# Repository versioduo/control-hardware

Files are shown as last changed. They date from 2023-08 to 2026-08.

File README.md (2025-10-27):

# control-hardware

⚙️ Instrument Controller

## Board

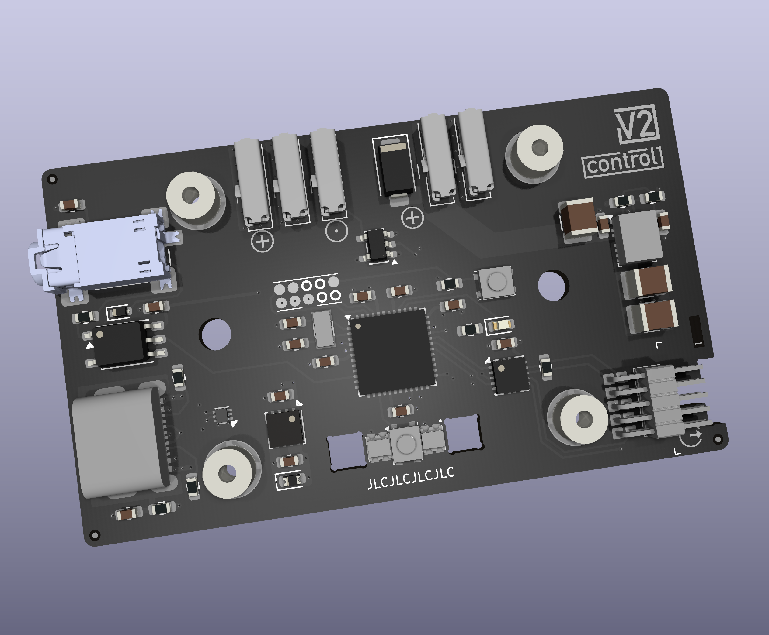
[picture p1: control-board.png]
board


## Schematic

[PDF](control.pdf)

## Bill Of Materials

[Interactive BOM](https://htmlpreview.github.io/?https://github.com/versioduo/control-hardware/main/control-bom.html)

# Copying
Anyone can use this public domain work without having to seek authorisation, no one can ever own it.

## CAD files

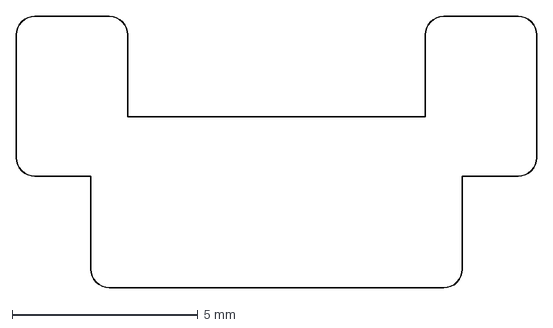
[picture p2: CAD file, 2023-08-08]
button-laser.dxf
14.0 x 7.30 mm

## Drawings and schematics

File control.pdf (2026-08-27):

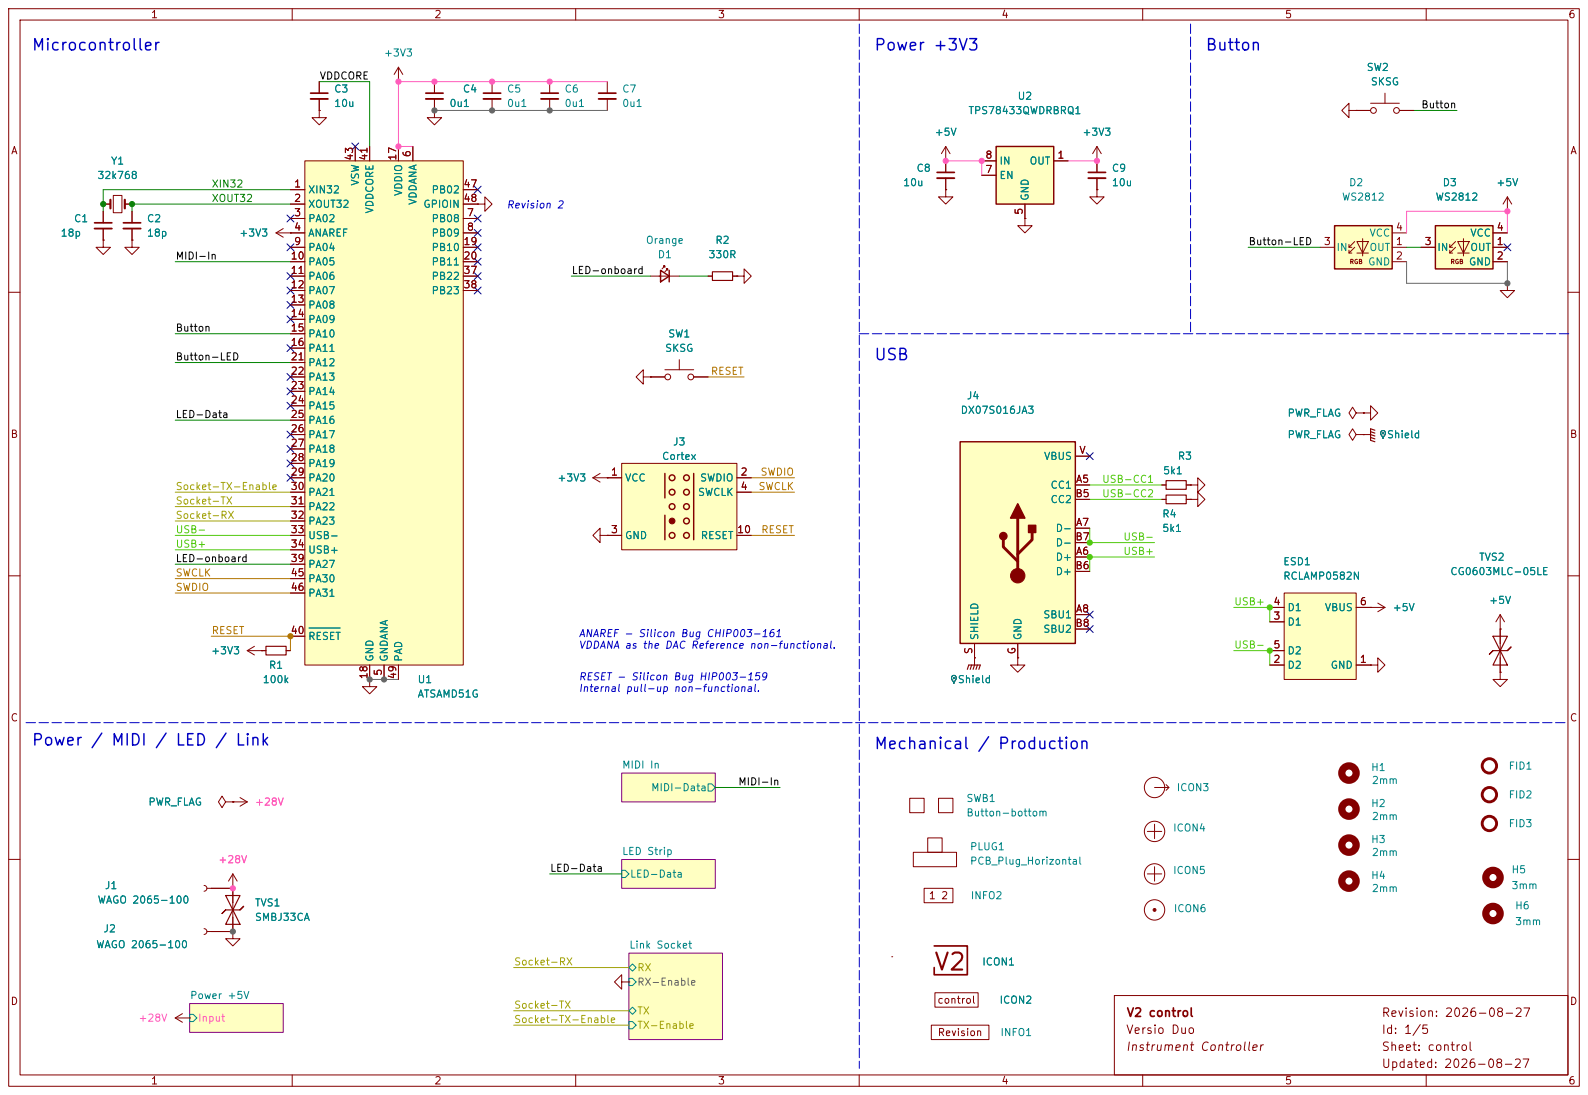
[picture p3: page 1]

VDDANA as the DAC Reference non-functional. Microcontroller

Button Socket-RX USB-

LED Strip MIDI-Data MIDI In +3V3

MIDI-In Button-LED
LED-onboard SWCLK

Internal pull-up non-functional. ANAREF - Silicon Bug CHIP003-161

Link Socket LED-Data

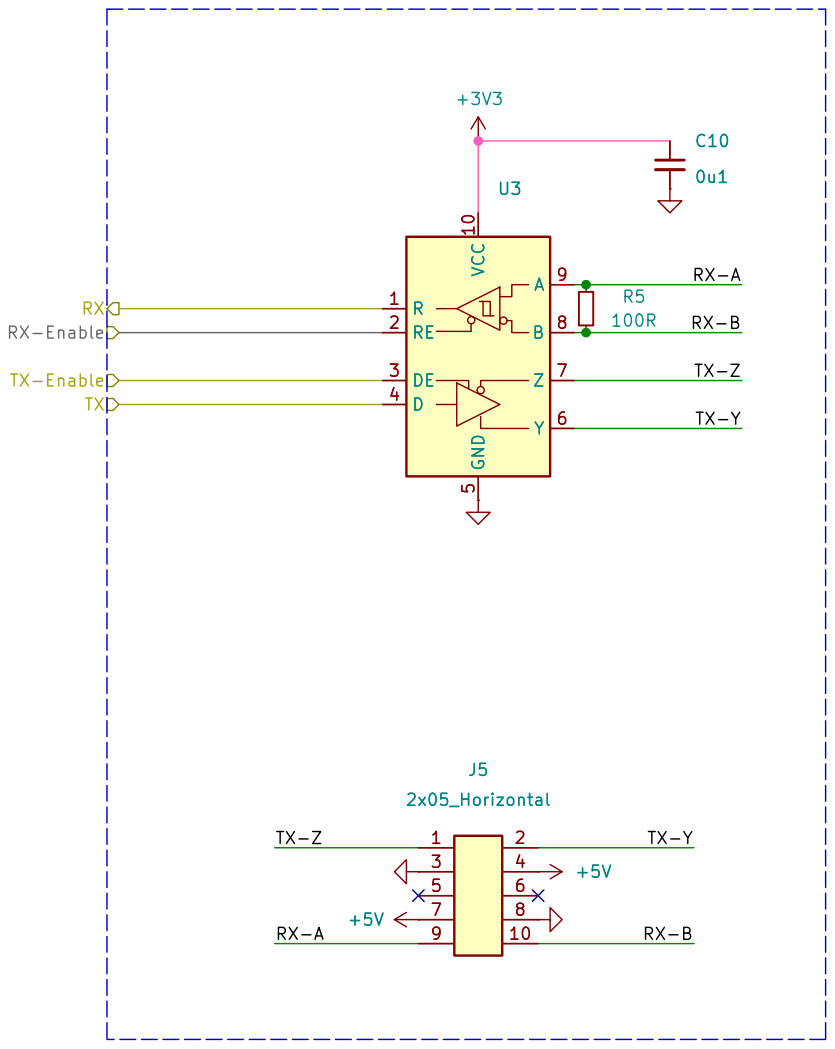
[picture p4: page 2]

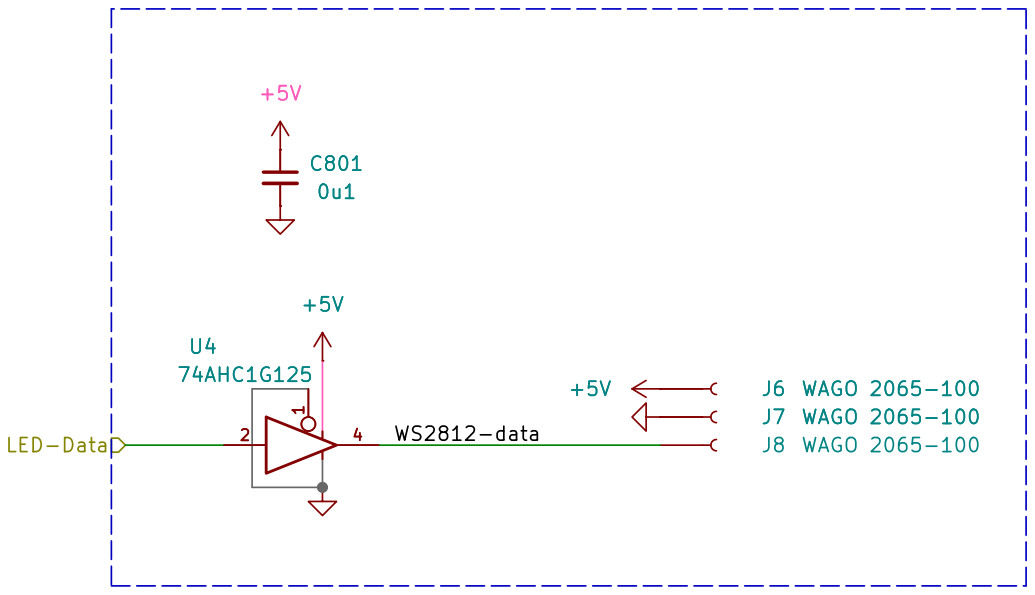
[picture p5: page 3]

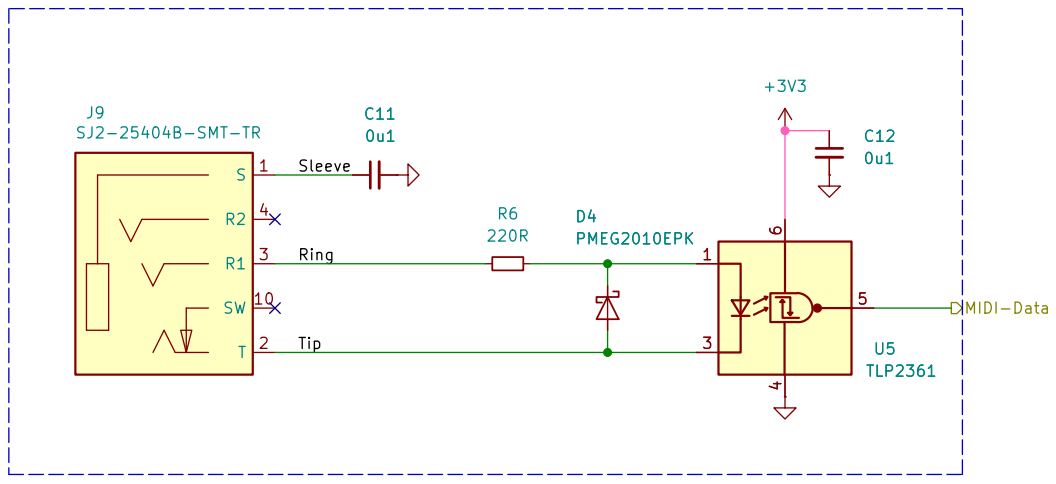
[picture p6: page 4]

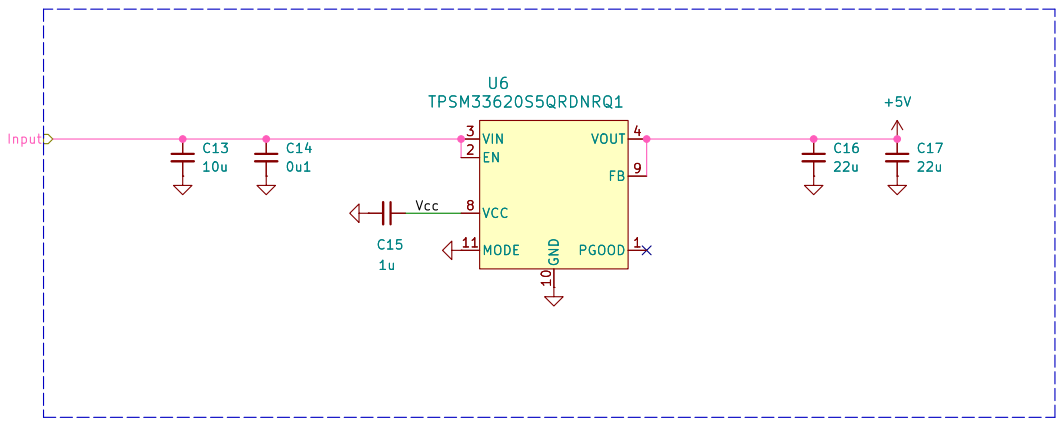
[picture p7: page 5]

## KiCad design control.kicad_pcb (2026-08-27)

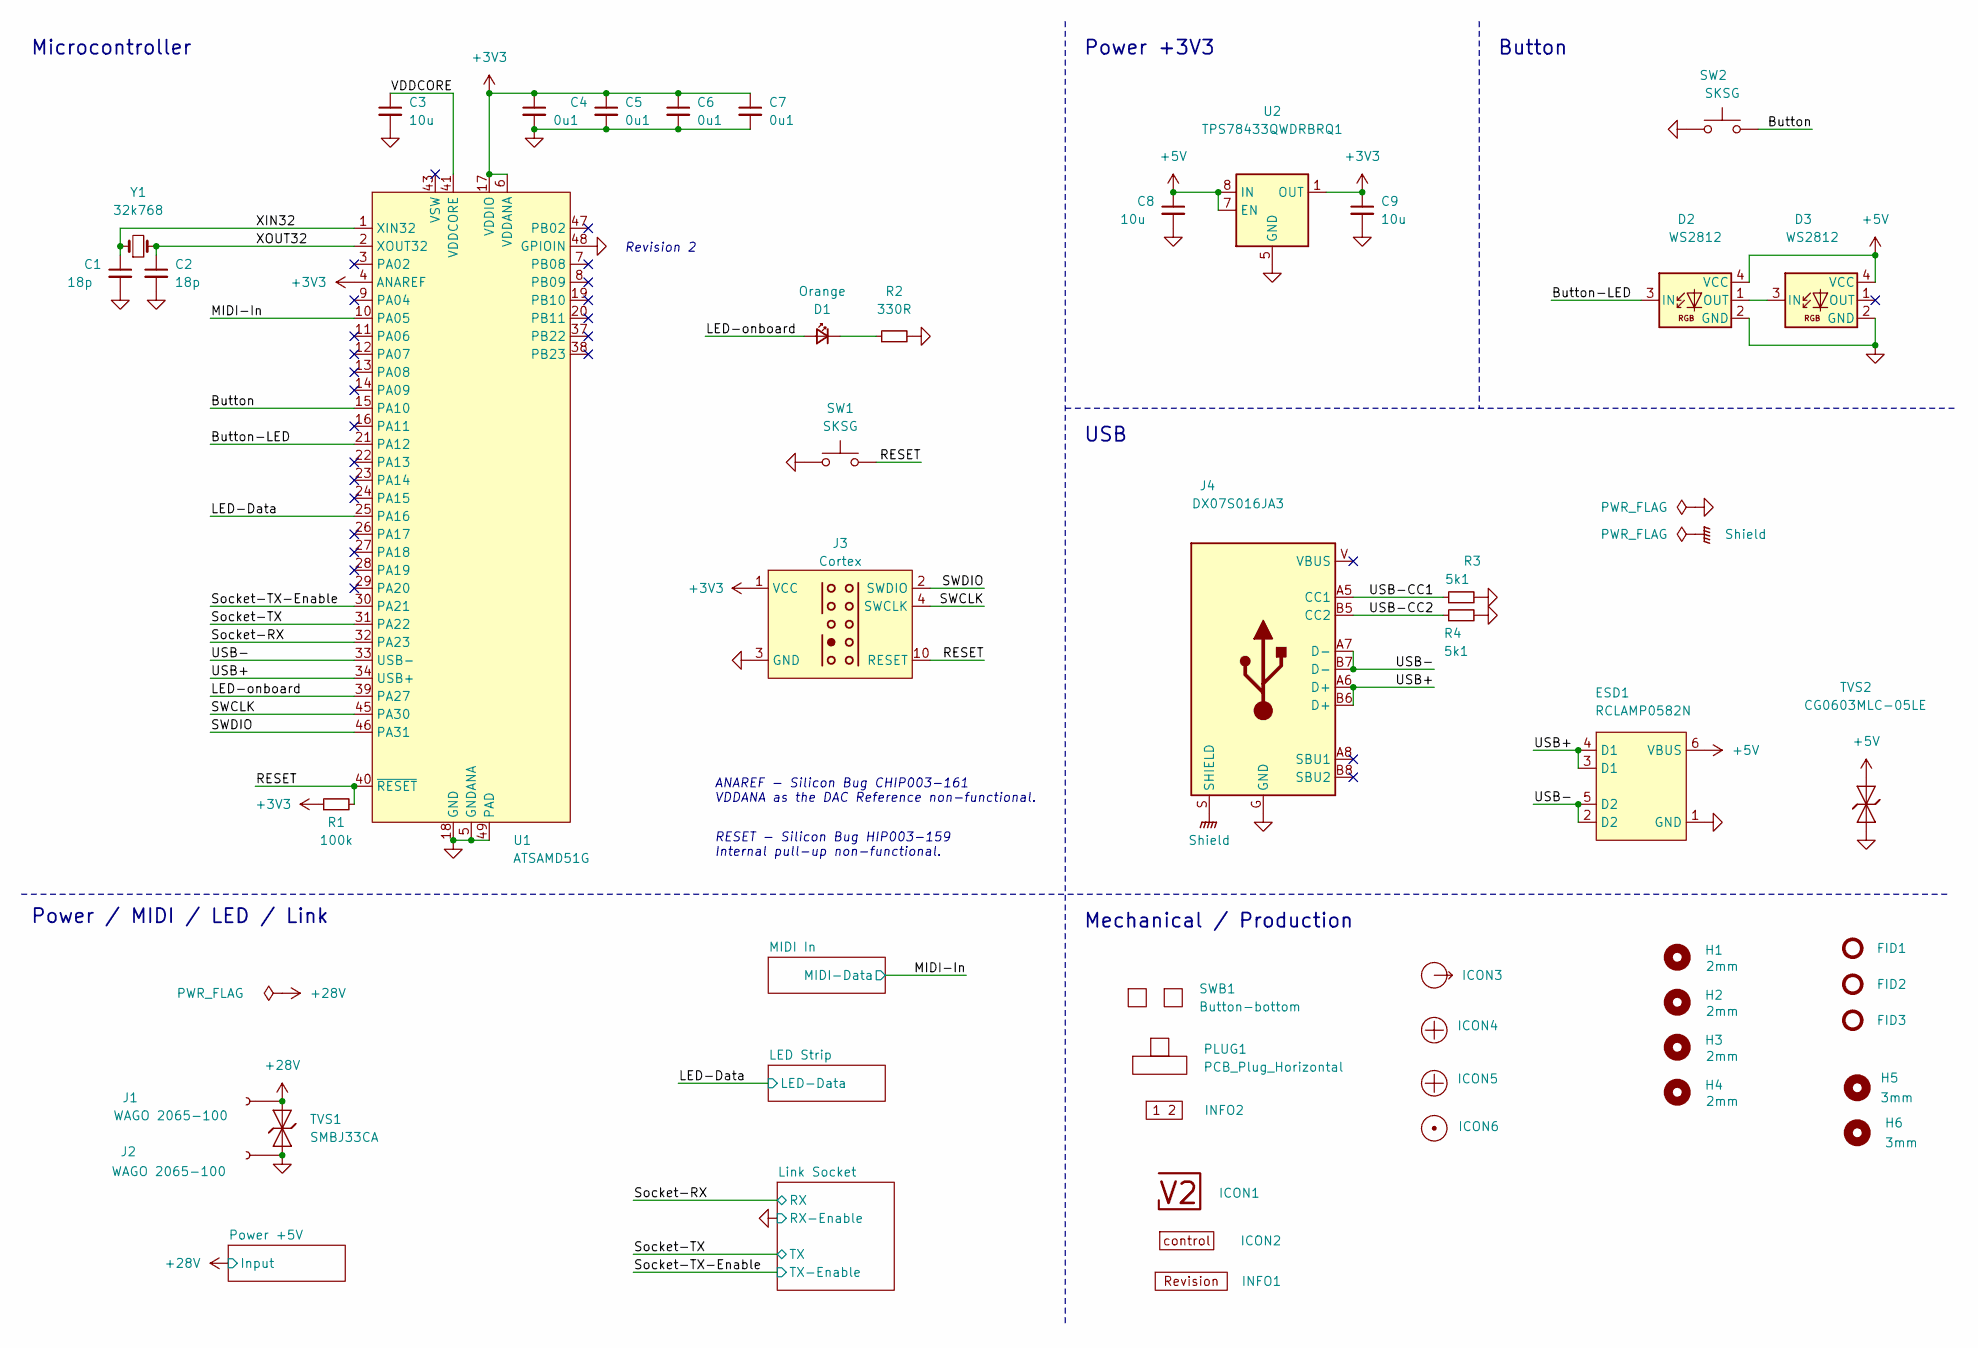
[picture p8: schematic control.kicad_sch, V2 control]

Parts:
C1, C2: 18p; C_1608; Rating 50V; Mouser 810-CGA3E2C0G1H180J
C3: 10u; C_1608; Rating 10V; Mouser 810-C1608X6S1A106M
C4, C5, C6, C7: 0u1; C_1608; Rating 50V; Mouser 810-CGA3E2X7R1H104MA
C8, C9: 10u; C_2012; Rating 25V; Mouser 810-C2012X5R1E106K
D1: Orange; LED_1608; Rating 605nm; Mouser 755-SML-D12D1WT86
D2, D3: WS2812; WS2812-2020; Rating 15mA; LCSC C965555
ESD1: RCLAMP0582N; SLP1210N6; Rating 20kV; Mouser 947-RCLAMP0582N.TCT
FID1, FID2, FID3: Fiducial_Paste; Fiducial_0.5mm_Mask1mm_Paste
H1, H2, H3, H4: 2mm; MountingHole_2mm
H5, H6: 3mm; MountingHole_3mm
ICON1: V2-logo; Logo_Small
ICON2: Board_control; Board_control_Small
ICON3: Arrow_Out
ICON4, ICON5: Plus; Plus_Small
ICON6: Dot; Dot_Small
INFO1: Revision
INFO2: Layer_Numbers-4
J1, J2: WAGO 2065-100; 2065-100; Rating 9A
J3: Cortex
J4: DX07S016JA3; JAE_DX07S016JA3; Rating USB2.0; Mouser 656-DX07S016JA3R1500
PLUG1: PCB_Plug_Horizontal
R1: 100k; R_1608; Rating 100mW; Mouser 71-CRCW0603100KFKEAC
R2: 330R; R_1608; Rating 100mW; Mouser 71-CRCW0603330RFKEAC
R3, R4: 5k1; R_1608; Rating 100mW; Mouser 71-CRCW06035K10FKEAC
SW1, SW2: SKSG; Rating 1.6N; Mouser 688-SKSGACE010
SWB1: Button-bottom; PCB_Button-bottom
TVS1: SMBJ33CA; D_SMB; Rating 33V; Mouser 652-SMBJ33CA-Q
TVS2: CG0603MLC-05LE; D_1608; Rating 5V; Mouser 652-CG0603MLC-05LE
U1: ATSAMD51G; QFN-48-1EP_7x7mm_P0.5mm_EP5.45x5.45mm_ThermalVias; Rating Cortex-M4F; Mouser 556-ATSAMD51G19AMU
U2: TPS78433QWDRBRQ1; VSON-8-1_3x3mm_P0.65_EP1.65x2.4mm; Rating 300mA; Mouser 595-TPS78433QWDRBRQ1
Y1: 32k768; Crystal_SMD_3215-2Pin_3.2x1.5mm; Rating 10ppm; Mouser 815-ABS0716632.768KT

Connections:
+3V3: C4.1, C5.1, C6.1, C7.1, C9.1, J3.1 (VCC), R1.1, U1.4 (ANAREF), U1.6 (VDDANA), U1.17 (VDDIO), U1.36 (VDDIO), U1.44 (VDDIO), U2.1 (OUT); also elsewhere on the board
+5V: C8.1, D2.4 (VCC), D3.4 (VCC), ESD1.6 (VBUS), TVS2.2 (A), U2.6 (EN), U2.7 (EN), U2.8 (IN); also elsewhere on the board
+28V: J1.1, TVS1.2 (A); also elsewhere on the board
/Button: SW2.2, U1.15 (PA10)
/Button-LED: D2.3 (IN), U1.21 (PA12)
/LED-Data: U1.25 (PA16); also elsewhere on the board
/LED-onboard: D1.2 (A), U1.39 (PA27)
/MIDI-In: U1.10 (PA05); also elsewhere on the board
/RESET: J3.10 (RESET), R1.2, SW1.2, U1.40 (~RESET)
/SWCLK: J3.4 (SWCLK), U1.45 (PA30)
/SWDIO: J3.2 (SWDIO), U1.46 (PA31)
/Shield: J4.S (SHIELD)
/Socket-RX: U1.32 (PA23); also elsewhere on the board
/Socket-TX: U1.31 (PA22); also elsewhere on the board
/Socket-TX-Enable: U1.30 (PA21); also elsewhere on the board
/USB+: ESD1.3 (D1), ESD1.4 (D1), J4.A6 (D+), J4.B6 (D+), U1.34 (USB+)
/USB-: ESD1.2 (D2), ESD1.5 (D2), J4.A7 (D-), J4.B7 (D-), U1.33 (USB-)
/USB-CC1: J4.A5 (CC1), R3.1
/USB-CC2: J4.B5 (CC2), R4.1
/VDDCORE: C3.1, U1.41 (VDDCORE)
/XIN32: C1.1, U1.1 (XIN32), Y1.1
/XOUT32: C2.1, U1.2 (XOUT32), Y1.2
GND: C1.2, C2.2, C3.2, C4.2, C5.2, C6.2, C7.2, C8.2, C9.2, D2.2 (GND), D3.2 (GND), ESD1.1 (GND), J2.1, J3.3 (GND), J3.5 (GND), J4.G (GND), R2.2, R3.2, R4.2, SW1.1, SW2.1, TVS1.1 (K), TVS2.1 (K), U1.5 (GNDANA), U1.18 (GND), U1.35 (GND), U1.42 (GND), U1.48 (GPIOIN), U1.49 (PAD), U2.5 (GND), U2.9 (GND); also elsewhere on the board
unnamed: D1.1 (K), R2.1
unnamed: D2.1 (OUT), D3.3 (IN)

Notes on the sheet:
ANAREF -  Silicon Bug CHIP003-161 VDDANA as the DAC Reference non-functional.
Power / MIDI / LED / Link
RESET -  Silicon Bug HIP003-159 Internal pull-up non-functional.
Button
Revision 2
Power +3V3
Mechanical / Production
Microcontroller
USB

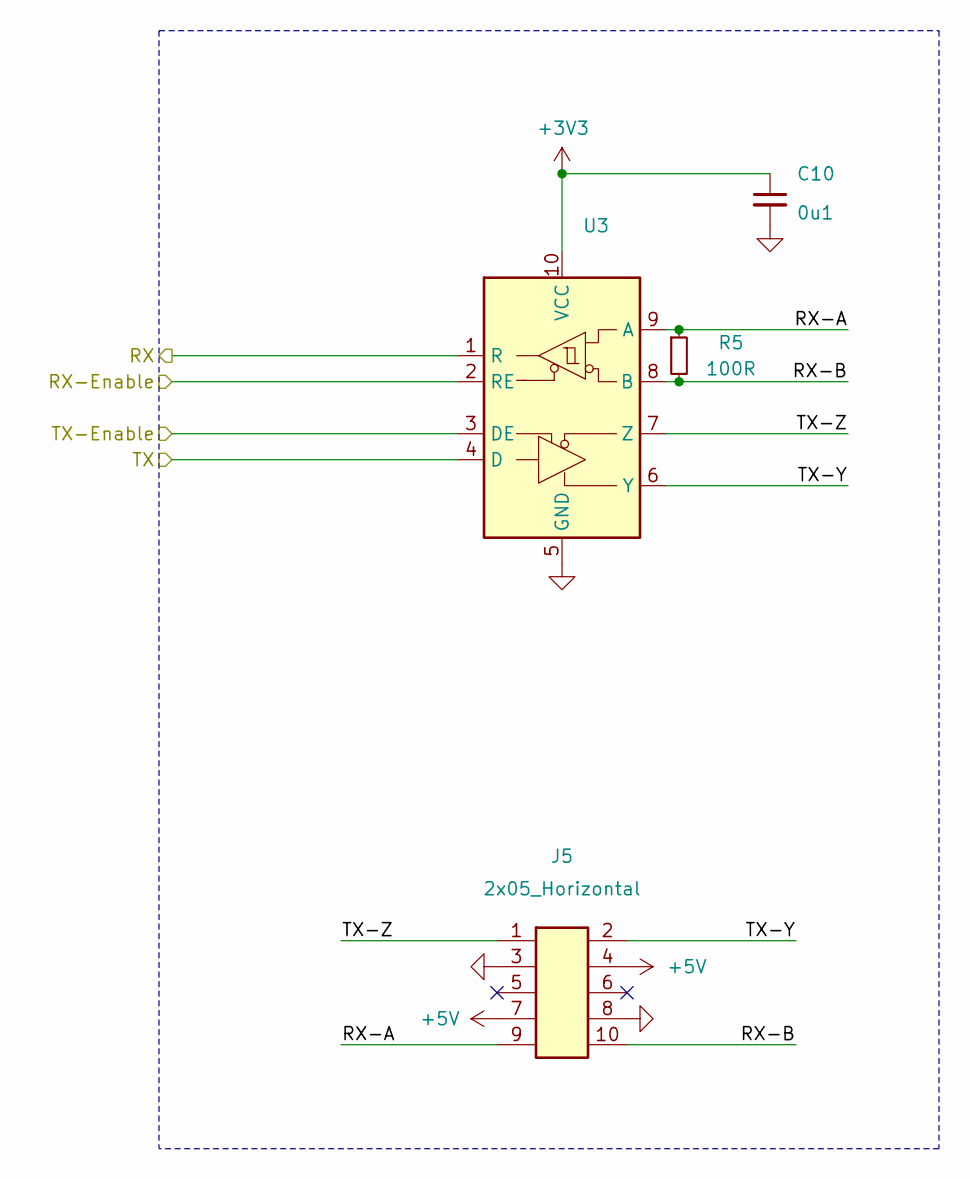
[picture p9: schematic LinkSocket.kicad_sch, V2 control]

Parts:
C10: 0u1; C_1608; Rating 50V; Mouser 810-CGA3E2X7R1H104MA
J5: 2x05_Horizontal; PinHeader_2x05_P1.27mm_Horizontal; Rating 1A; Mouser 649-200211120001T4LF
R5: 100R; R_1608; Rating 330mW; Mouser 71-CRCW0603100RFKEAH
U3: VSON-10-4-1EP_3x3mm_P0.5mm_EP1.65x2.4mm_ThermalVias

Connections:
+3V3: C10.1, U3.10 (VCC); also elsewhere on the board
+5V: J5.4, J5.7; also elsewhere on the board
/Link Socket/RX-A: J5.9, R5.1, U3.9 (A)
/Link Socket/RX-B: J5.10, R5.2, U3.8 (B)
/Link Socket/TX-Y: J5.2, U3.6 (Y)
/Link Socket/TX-Z: J5.1, U3.7 (Z)
/Socket-RX: U3.1 (R); also elsewhere on the board
/Socket-TX: U3.4 (D); also elsewhere on the board
/Socket-TX-Enable: U3.3 (DE); also elsewhere on the board
GND: C10.2, J5.3, J5.8, U3.2 (RE), U3.5 (GND), U3.11 (GND); also elsewhere on the board

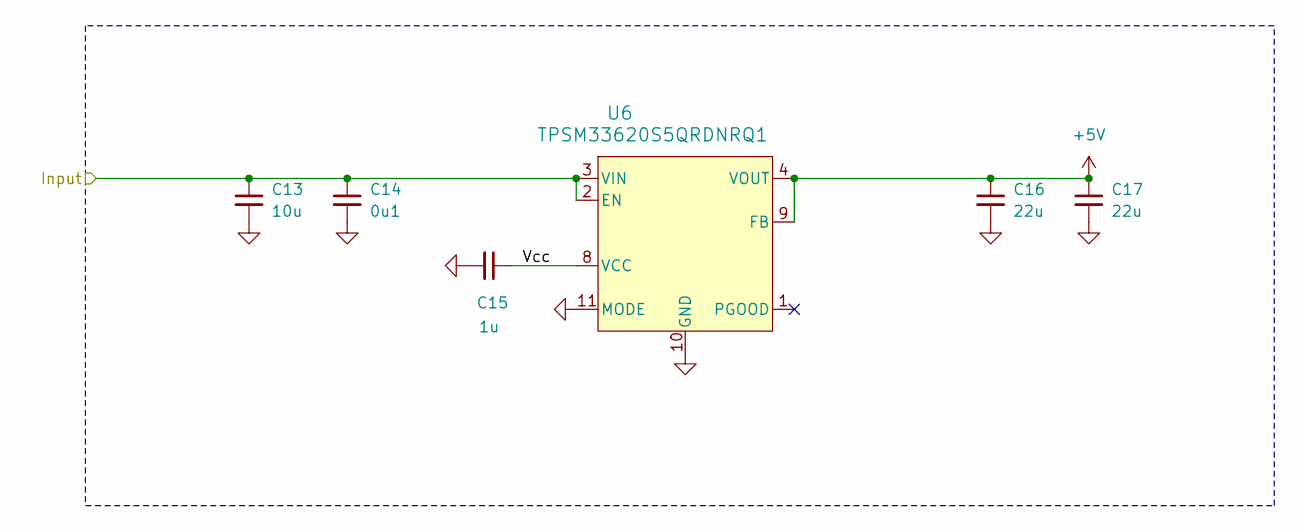
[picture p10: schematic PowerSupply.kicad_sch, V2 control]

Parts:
C13: 10u; C_3225; Rating 50V; Mouser 810-CNC6P1X7R1H106K2
C14: 0u1; C_1608; Rating 50V; Mouser 810-CGA3E2X7R1H104MA
C15: 1u; C_1608; Rating 50V; Mouser 810-CGA3E3X7R1H105K0
C16, C17: 22u; C_3225; Rating 25V; Mouser 810-CGA6P3X7R1E226M5
U6: TPSM33620S5QRDNRQ1; QFN-11; Rating 2A; Mouser 595-SM33620S5QRDNRQ1

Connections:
+5V: C16.1, C17.1, U6.4 (VOUT), U6.9 (FB); also elsewhere on the board
+28V: C13.1, C14.1, U6.2 (EN), U6.3 (VIN); also elsewhere on the board
/Power +5V/Vcc: C15.1, U6.8 (VCC)
GND: C13.2, C14.2, C15.2, C16.2, C17.2, U6.10 (GND), U6.11 (MODE); also elsewhere on the board

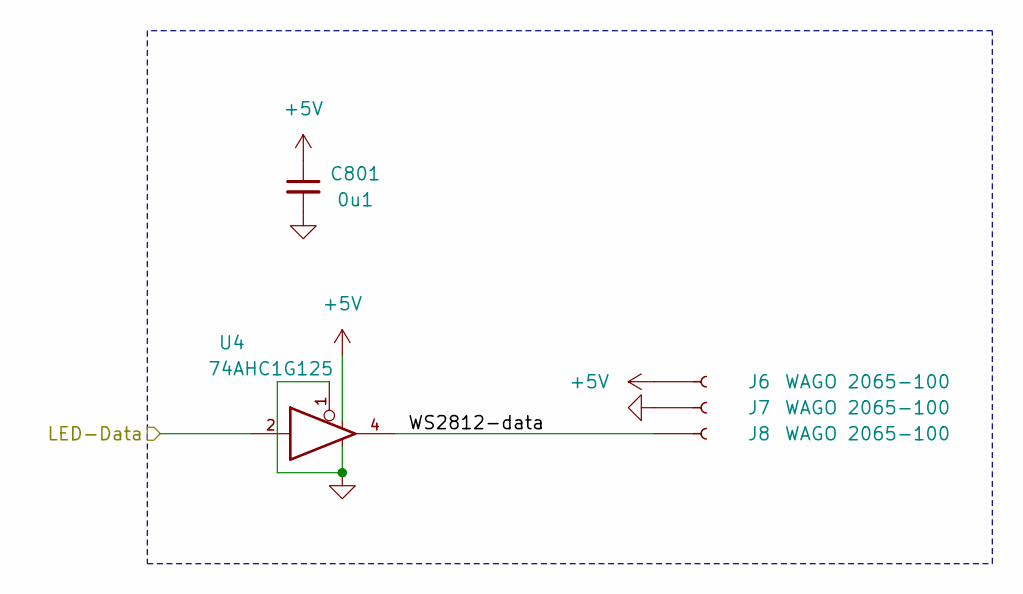
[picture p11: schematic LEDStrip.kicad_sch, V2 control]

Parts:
C801: 0u1; C_1608; Rating 50V; Mouser 810-CGA3E2X7R1H104MA
J6, J7, J8: WAGO 2065-100; 2065-100; Rating 9A
U4: 74AHC1G125; SOT-23-5; Rating 8mA; Mouser 595-SN74AHC1G125DBVR

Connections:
+5V: C801.1, J6.1, U4.5; also elsewhere on the board
/LED Strip/WS2812-data: J8.1, U4.4
/LED-Data: U4.2; also elsewhere on the board
GND: C801.2, J7.1, U4.1, U4.3; also elsewhere on the board

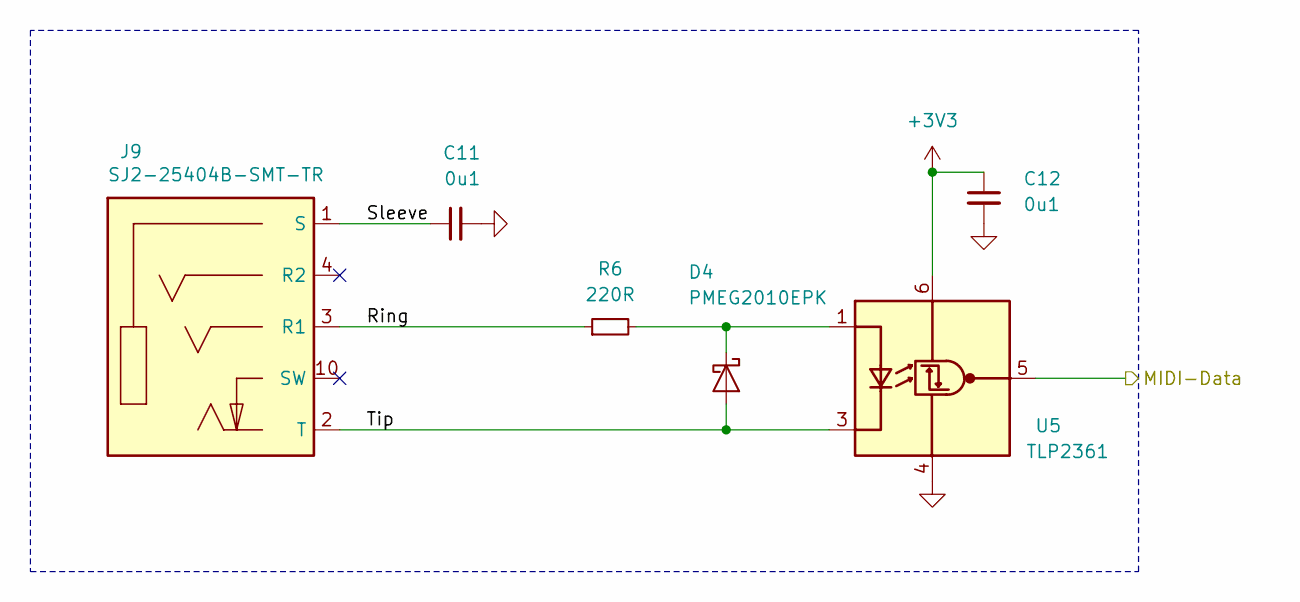
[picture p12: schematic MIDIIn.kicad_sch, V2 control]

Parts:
C11, C12: 0u1; C_1608; Rating 50V; Mouser 810-CGA3E2X7R1H104MA
D4: PMEG2010EPK; D_SOD-1608; Rating 20V; Mouser 771-PMEG2010EPK
J9: SJ2-25404B-SMT-TR; CUI_SJ2-25404B-SMT-TR; Rating 2.5mm; Mouser 490-SJ2-25404BSMT-TR
R6: 220R; R_1608; Rating 330mW; Mouser 71-CRCW0603220RFKEAH
U5: TLP2361; SO-5-6_4.55x3.7mm_P1.27mm; Rating 15Mbps; Mouser 757-TLP2361TPRE

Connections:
+3V3: C12.1, U5.6 (VDD); also elsewhere on the board
/MIDI In/Ring: J9.3 (R1), R6.1
/MIDI In/Sleeve: C11.1, J9.1 (S)
/MIDI In/Tip: D4.2 (A), J9.2 (T), U5.3 (K)
/MIDI-In: U5.5 (VO); also elsewhere on the board
GND: C11.2, C12.2, U5.4 (GND); also elsewhere on the board
unnamed: D4.1 (K), R6.2, U5.1 (A)

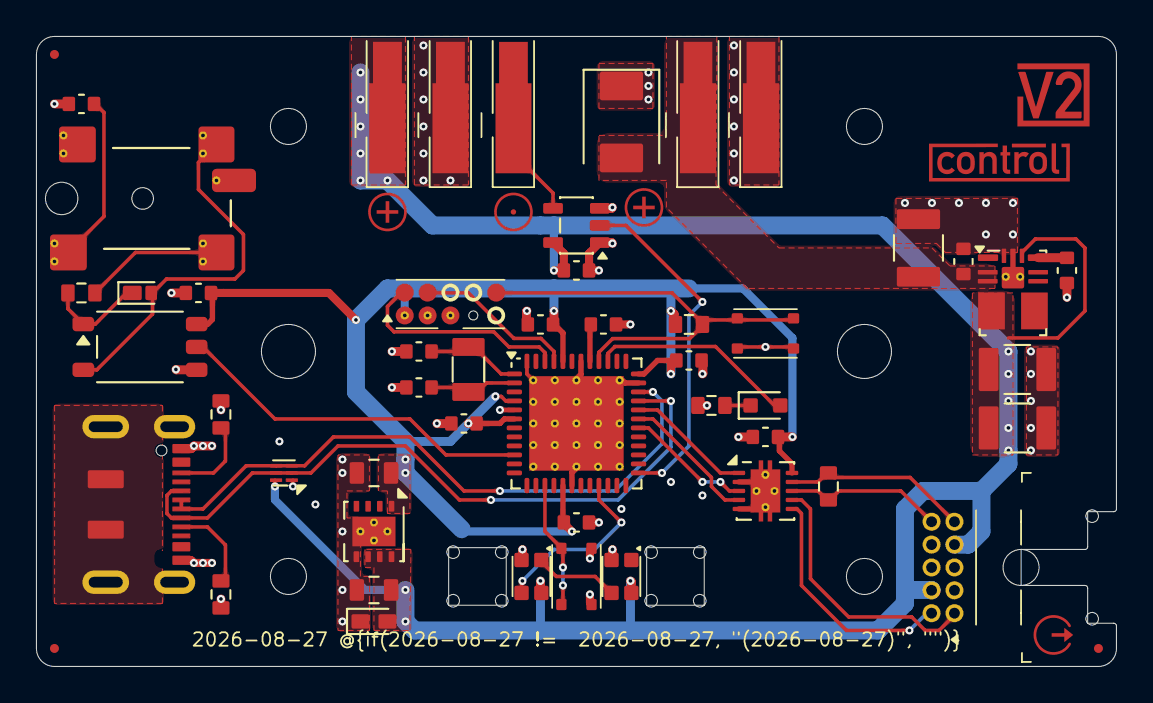
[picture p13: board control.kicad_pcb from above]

Board: 4 copper layers, 60.0 x 35.0 mm, 68 parts (0 on the bottom side), 34 nets.

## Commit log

2024-03-28 Update to Kicad 8
    [LEDStrip.kicad_sch, LinkSocket.kicad_sch, MIDIIn.kicad_sch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]
2024-03-28 Update DCDC
    [LEDStrip.kicad_sch, LinkSocket.kicad_sch, MIDIIn.kicad_sch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]
2024-06-20 Replace icons
    [LEDStrip.kicad_sch, LinkSocket.kicad_sch, MIDIIn.kicad_sch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]
2024-07-17 Update TRS socket
    [LEDStrip.kicad_sch, LinkSocket.kicad_sch, MIDIIn.kicad_sch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]
